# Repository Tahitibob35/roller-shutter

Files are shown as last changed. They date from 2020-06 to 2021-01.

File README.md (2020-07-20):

# roller-shutter
Somfy roller shutter controlled by an ESP32

## Materials

### ESP32 from azdelivery

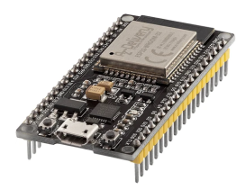
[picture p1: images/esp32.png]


### RF433 module

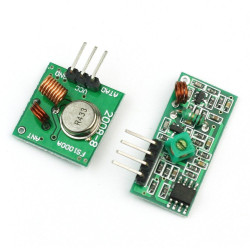
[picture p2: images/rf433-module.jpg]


### 433.42MHz oscillator

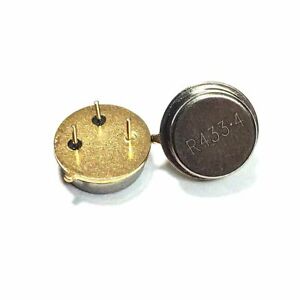
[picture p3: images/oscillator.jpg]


### Somfy RTS module

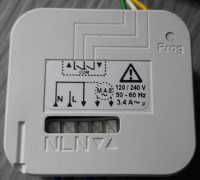
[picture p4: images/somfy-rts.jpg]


## First run or rescue mode

Keep pressed on the rescue button (pin 14) and press the ESP32 reset button.

The ESP32 start in rescue mode as an access point.

* Access point : "VoletRoulants"

* Default IP : 10.10.10.1

Configuration URL : http://roller/config

Set your wifi credentials in the wifi page and restart the ESP32.

* Home page URL : http://X.X.X.X

* Configuration page URL : http://X.X.X.X/config

## Attach a roller shutter



Press the "Prog" button 3 seconds

Go to the "Attacher" page and click on the desired roller shutter

## Screenshots

* Main page

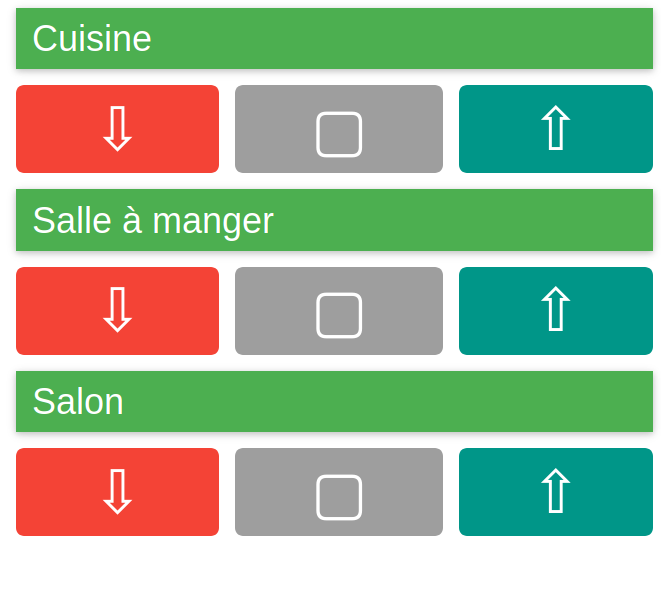
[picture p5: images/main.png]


* Configuration page

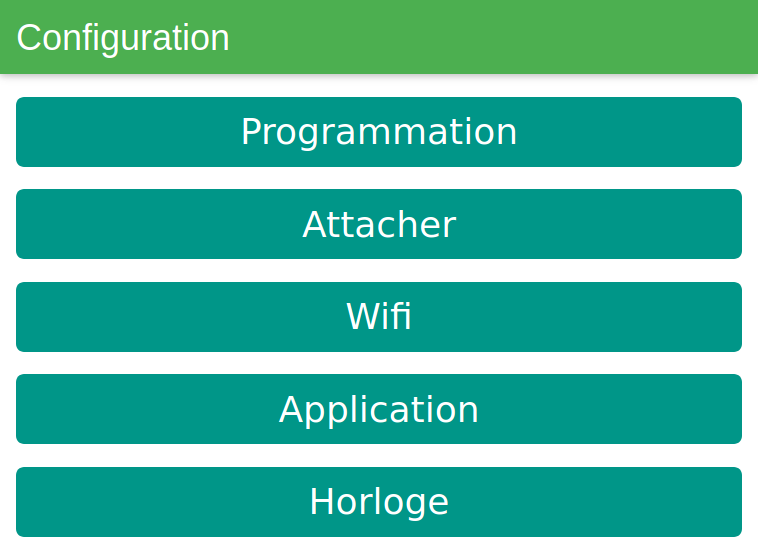
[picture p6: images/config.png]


* Programs page

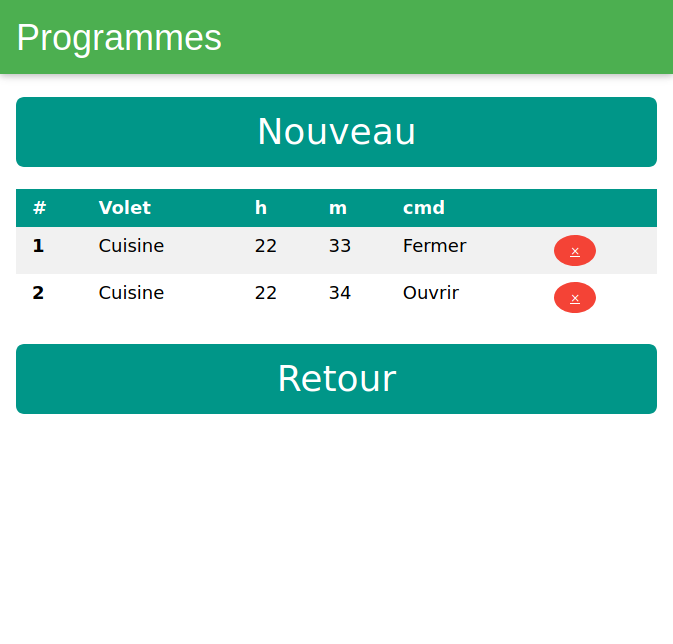
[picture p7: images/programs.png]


* Wifi page

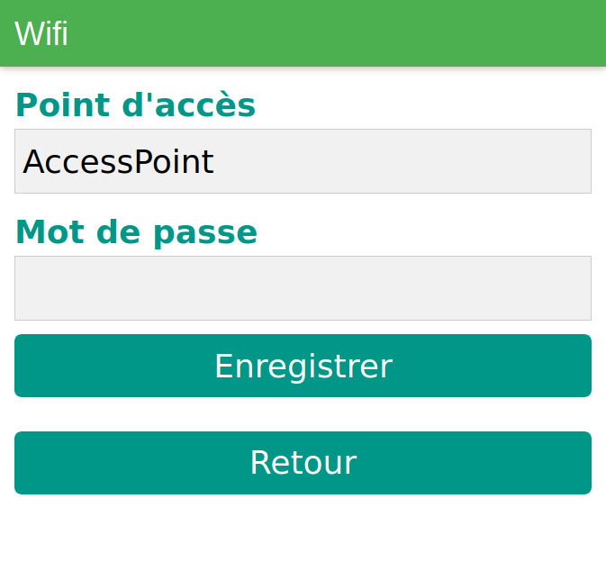
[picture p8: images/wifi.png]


* Clock page

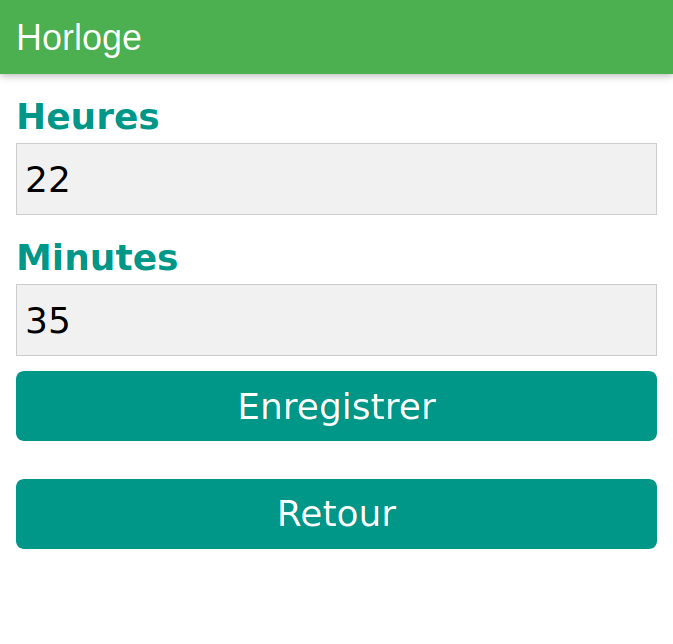
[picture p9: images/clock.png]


* Schema

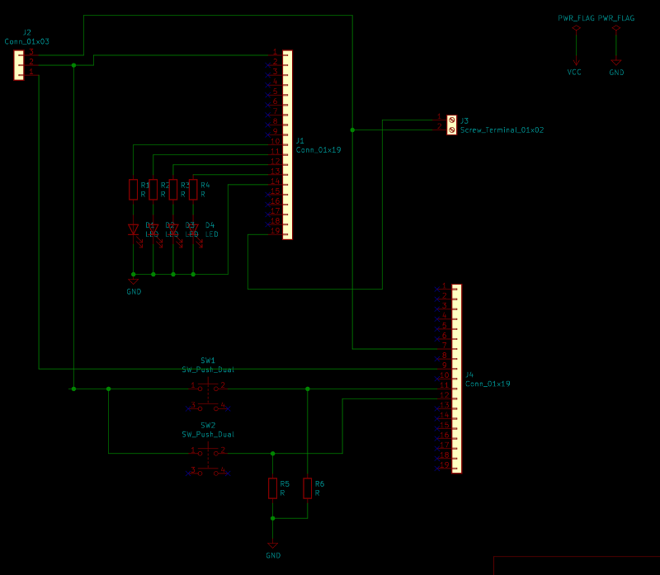
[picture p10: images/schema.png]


## Photos

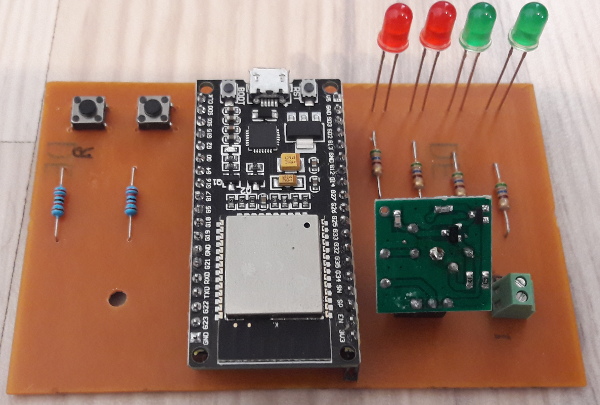
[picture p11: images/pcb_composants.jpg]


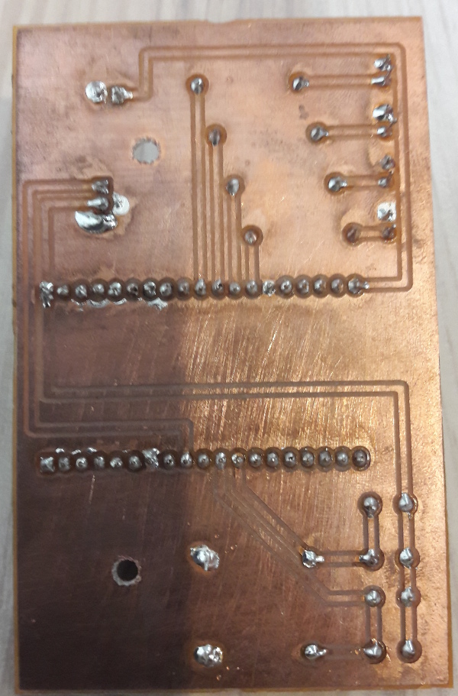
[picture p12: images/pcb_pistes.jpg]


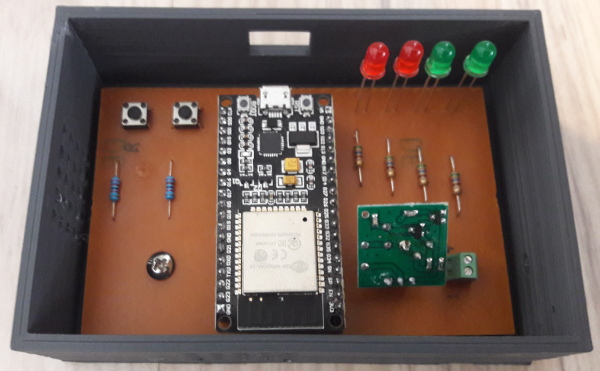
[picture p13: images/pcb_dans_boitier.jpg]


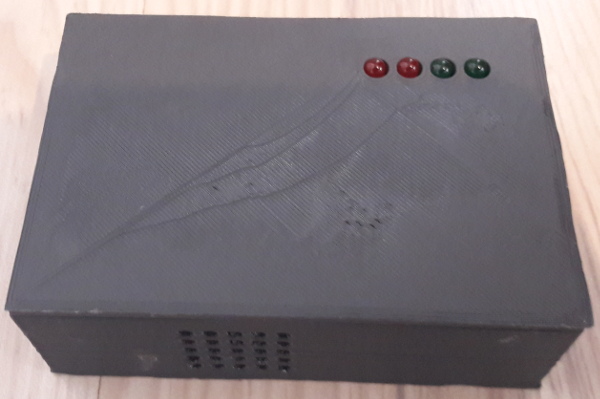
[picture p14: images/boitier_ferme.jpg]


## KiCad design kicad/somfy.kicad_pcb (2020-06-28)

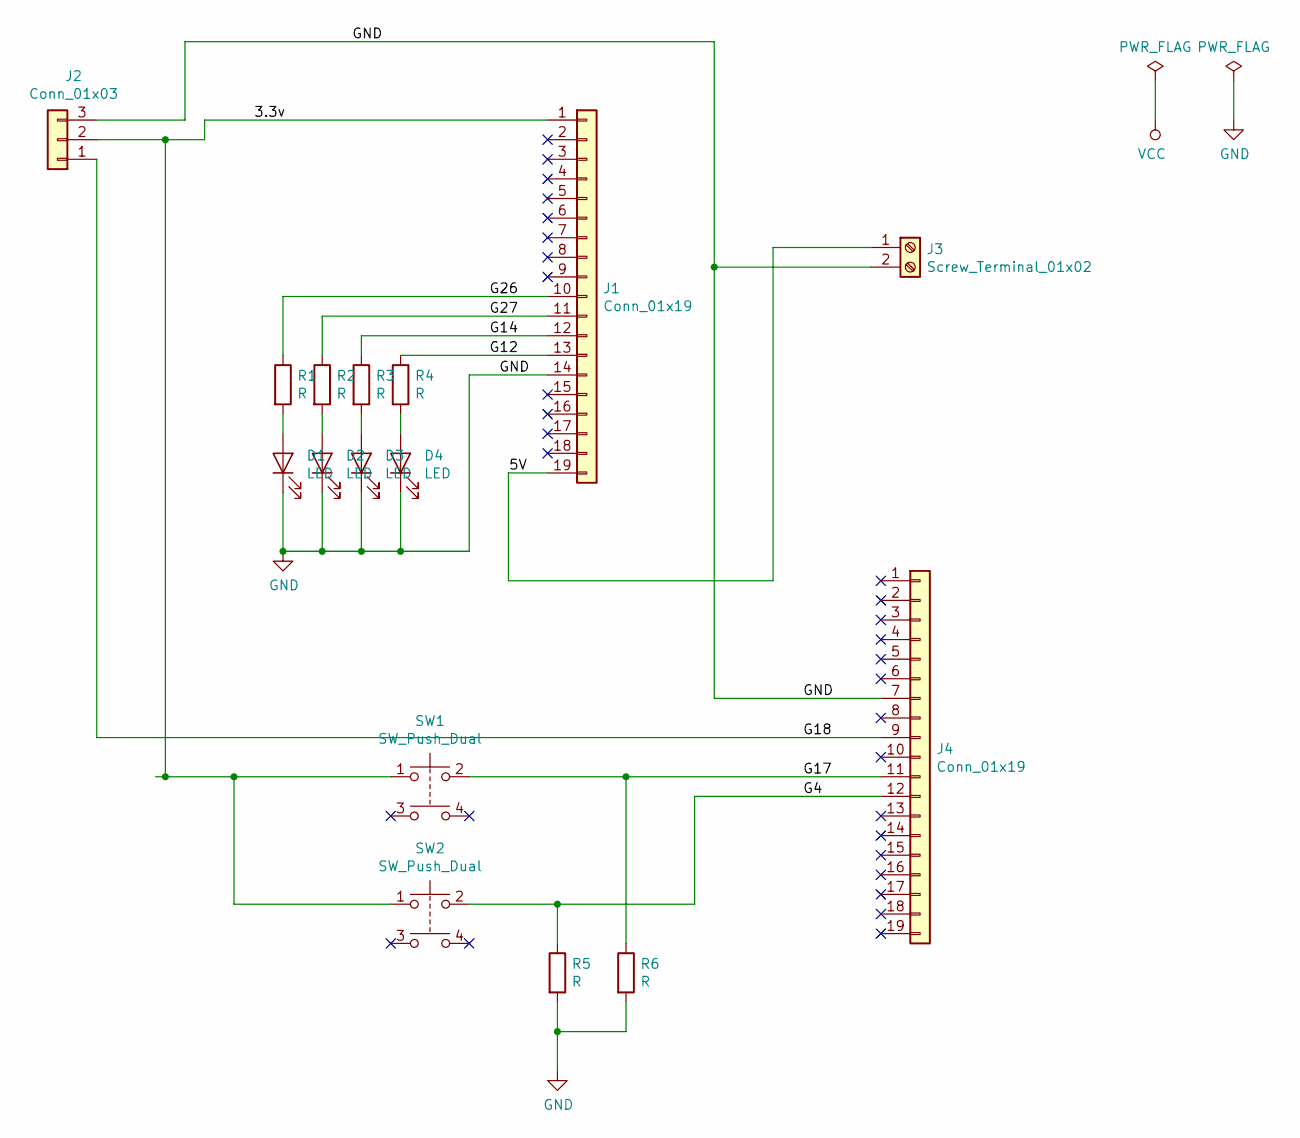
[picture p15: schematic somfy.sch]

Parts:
D1, D2, D3, D4: LED; LED_D3.0mm
J1, J4: Conn_01x19; PinHeader_1x19_P2.54mm_Vertical
J2: Conn_01x03; PinHeader_1x03_P2.54mm_Vertical
J3: Screw_Terminal_01x02; PinHeader_1x02_P2.54mm_Vertical
R1, R2, R3, R4, R5, R6: R; R_Axial_DIN0309_L9.0mm_D3.2mm_P15.24mm_Horizontal
SW1, SW2: SW_Push_Dual; SW_Tactile_Straight_KSA0Axx1LFTR

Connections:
/3.3v: J1.1, J2.2, SW1.1, SW2.1
/5V: J1.19, J3.1
/G4: J4.12, R5.1, SW2.2
/G12: J1.13, R4.1
/G14: J1.12, R3.1
/G17: J4.11, R6.1, SW1.2
/G18: J2.1, J4.9
/G26: J1.10, R1.1
/G27: J1.11, R2.1
GND: D1.1 (K), D2.1 (K), D3.1 (K), D4.1 (K), J1.14, J2.3, J3.2, J4.7, R5.2, R6.2
unnamed: D1.2 (A), R1.2
unnamed: D2.2 (A), R2.2
unnamed: D3.2 (A), R3.2
unnamed: D4.2 (A), R4.2

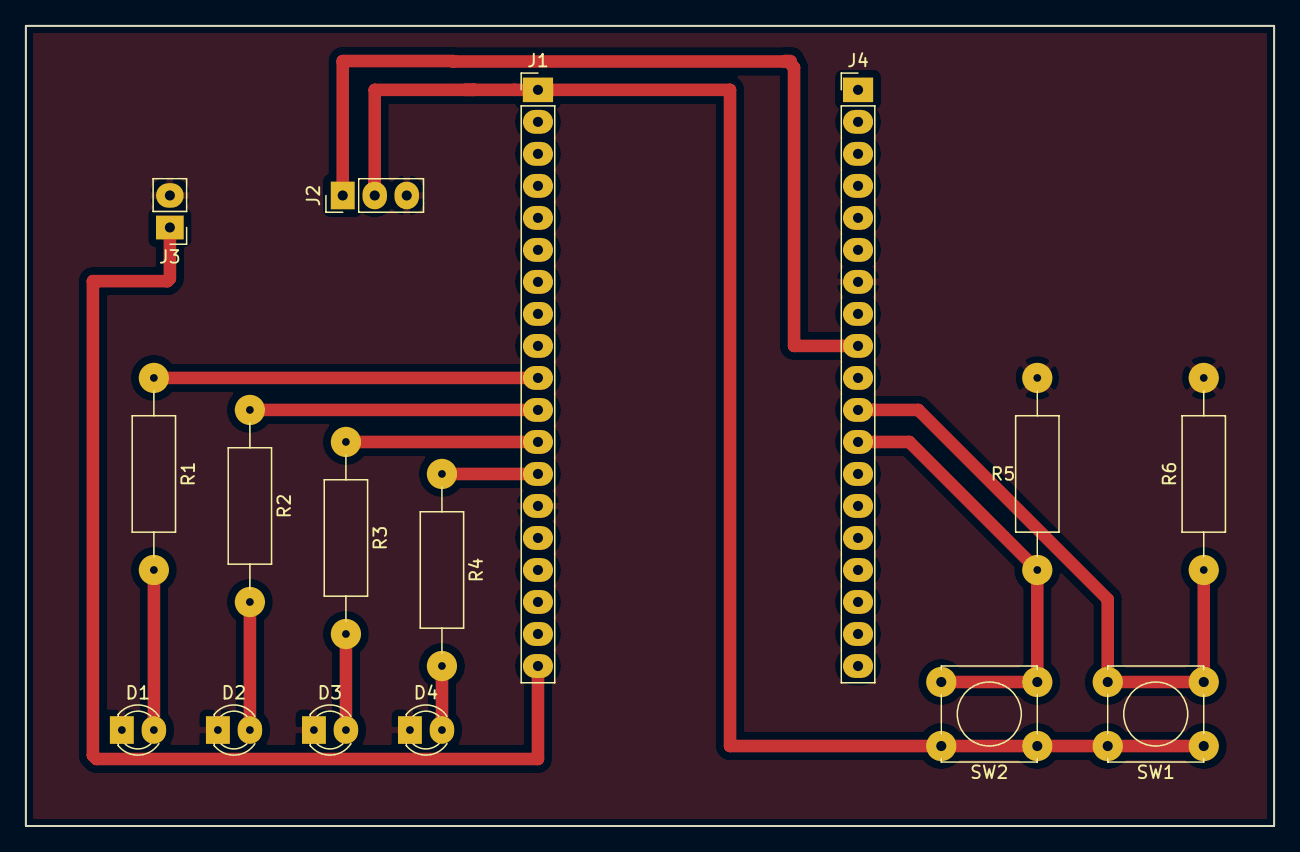
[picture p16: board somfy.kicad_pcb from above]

Board: 2 copper layers, 99.1 x 63.5 mm, 16 parts (0 on the bottom side), 14 nets.

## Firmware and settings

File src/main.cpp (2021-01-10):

#include "WiFi.h"

#include "rs_wifi.h"
#include "rs_webserver.h"
#include "prefs.h"
#include "rs_time.h"
#include "pins.h"
#include "misc.h"
#include "esp32-hal-cpu.h"
#include "rs_scheduledtasks.h"
#include "prgm.h"

int rescue_mode = 0;
const long interval = 2000;
unsigned long previousMillis = 0;
uint8_t previous_hour = 0;
uint8_t previous_minute = 0;
extern bool time_set;
bool wifi_connected;

void setup() {
  wifi_connected =  false;
  
  Serial.begin(115200);
  Serial.println("\n\n\n** Boot in progress....");

  setCpuFrequencyMhz(80);
  int cpuSpeed = getCpuFrequencyMhz();
  Serial.print("CPU Frequency :");
  Serial.println(cpuSpeed);

  pinMode(RESCUE_PIN, INPUT);
  pinMode(STATUS_LED_PIN, OUTPUT);
  pinMode(TX_LED_PIN, OUTPUT);

  digitalWrite(STATUS_LED_PIN, HIGH);
  digitalWrite(TX_LED_PIN, HIGH);

  rescue_mode = digitalRead(RESCUE_PIN);
  
  if (rescue_mode) {
    start_softap();
    enable_wifiBlinkTask();   
  }
  else {
    connect_to_wifi();
    setup_syslog();
    enable_checkWifiTask();
    if (inittime()) {
      digitalWrite(STATUS_LED_PIN, LOW);
      time_set = true;
    }
  }
  
  ws_config(rescue_mode);
  
  prefs_loadprgms();
  refresh_programTask();

  digitalWrite(TX_LED_PIN, LOW);

  write_output("End setup function");
}

void loop() {

  if (rescue_mode) {
    handle_dns_requests();
  }else
  {
    if(!time_set) {
      write_output("Main.Loop - Time not set, trying to get it...");
      if (inittime()) {
        digitalWrite(STATUS_LED_PIN, LOW);
        write_output("Main.Loop - Time set");
        time_set = true;
      }
    }
  }
  // Task scheduler
  execute_runner();  
}

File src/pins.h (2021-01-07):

#define RESCUE_PIN 17
#define STATUS_LED_PIN 12
#define TX_LED_PIN 26

#define RF433_PIN 18

#define TX_LED_PIN27 27
#define TX_LED_PIN26 26
#define BUTTON1_PIN34 34
#define BUTTON2_PIN35 35

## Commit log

2020-06-28 Add Kicad PCB files
    [somfy.kicad_pcb, somfy.sch]
2020-09-06 Fix time setup on startup
    [main.cpp, rs_time.cpp, rs_wifi.cpp]
2020-12-30 Feature: new api page (protected by token) Feature: write output to a syslog server Fix: ping default gateway for wifi health check
    [main.cpp, prefs.cpp, prefs.h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]
2021-01-08 Remove delay from Somfy move functions (replaced by a task)
    [rs_scheduledtasks.cpp]
